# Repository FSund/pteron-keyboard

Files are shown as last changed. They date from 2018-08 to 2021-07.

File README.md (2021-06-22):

# pteron keyboard
An ergonomic keyboard heavily inspired by the [Atreus](https://github.com/technomancy/atreus), [Iris](https://github.com/keebio/iris-case) and [Atreis](https://github.com/dekonnection/atreis) keyboards.

The name *Pteron* is the Ancient greek word for wing (and feather). This was inspired by *Chiroptera*, the scientific name (or order) of bats.
> The name “Chiroptera” derives from Ancient Greek: χείρ – cheir, “hand” and πτερόν – pteron, “wing”.
https://en.wikipedia.org/wiki/Bat#Etymology

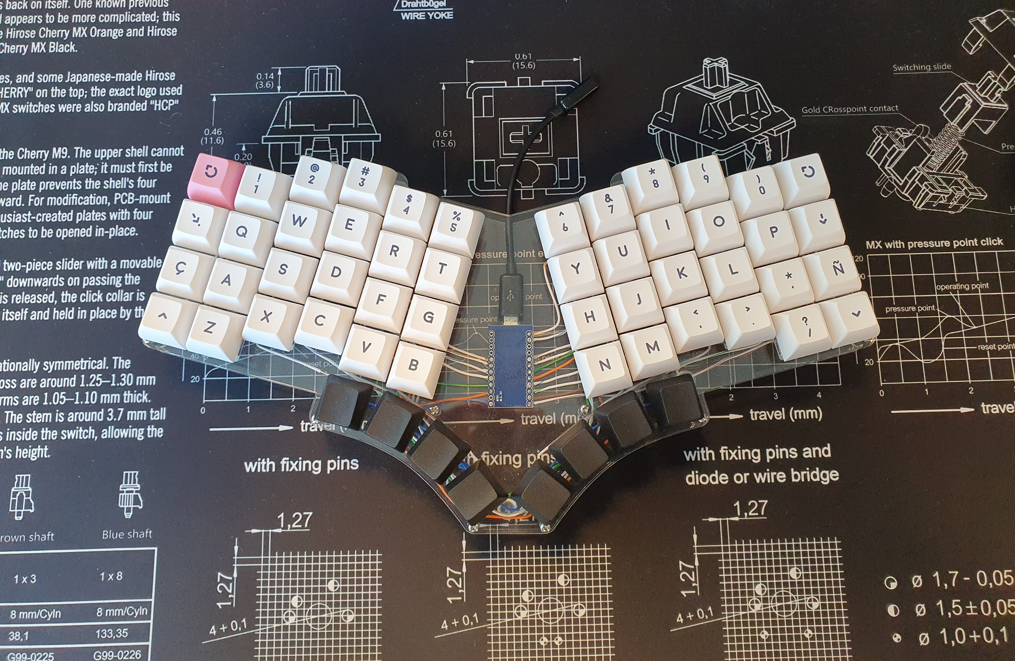
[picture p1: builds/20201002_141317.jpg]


Check the [builds](/builds/builds.md) folder for more photos. 
The 56-key version shown in the photo above is built using 9 mm brass spacers. It can theoretically be built using spacers as small as 5 mm, but that requires very strict cable management.

## Related projects
- PCB and acrylic case for the 56-key Pteron: https://github.com/kraken-jokes/pteron-pcb
- 36-key split version with PCB and acrylic case designs: https://github.com/harshitgoel96/pteron36-split-keyboard

## Styles
#### 38 keys
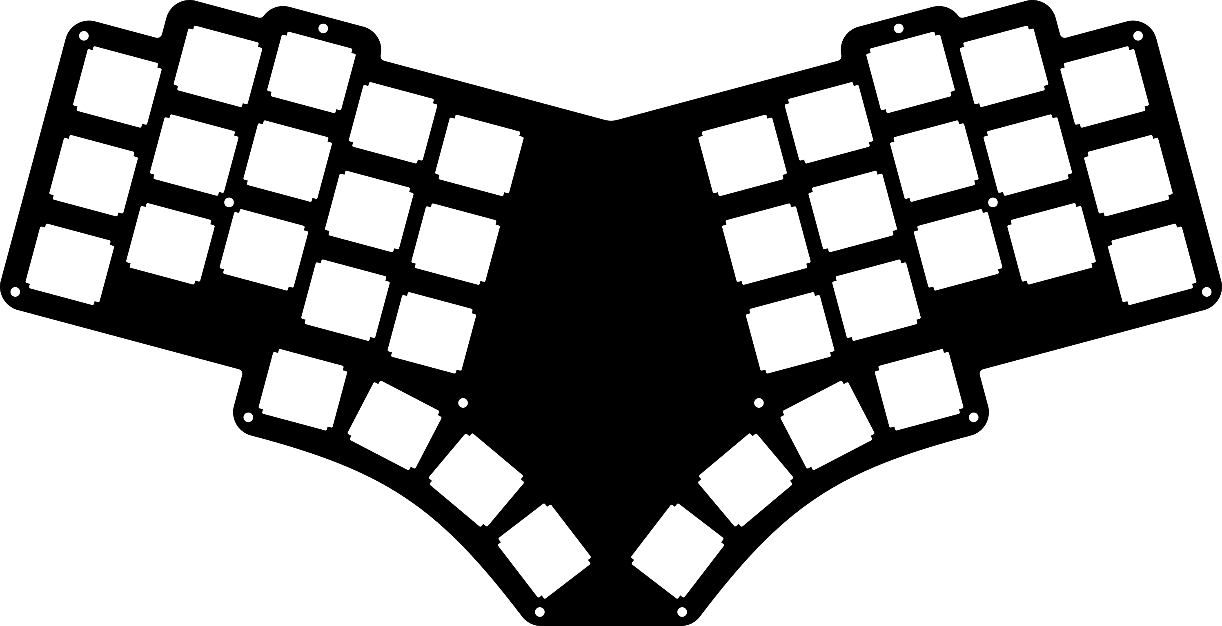
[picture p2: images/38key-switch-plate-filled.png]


#### 44 keys
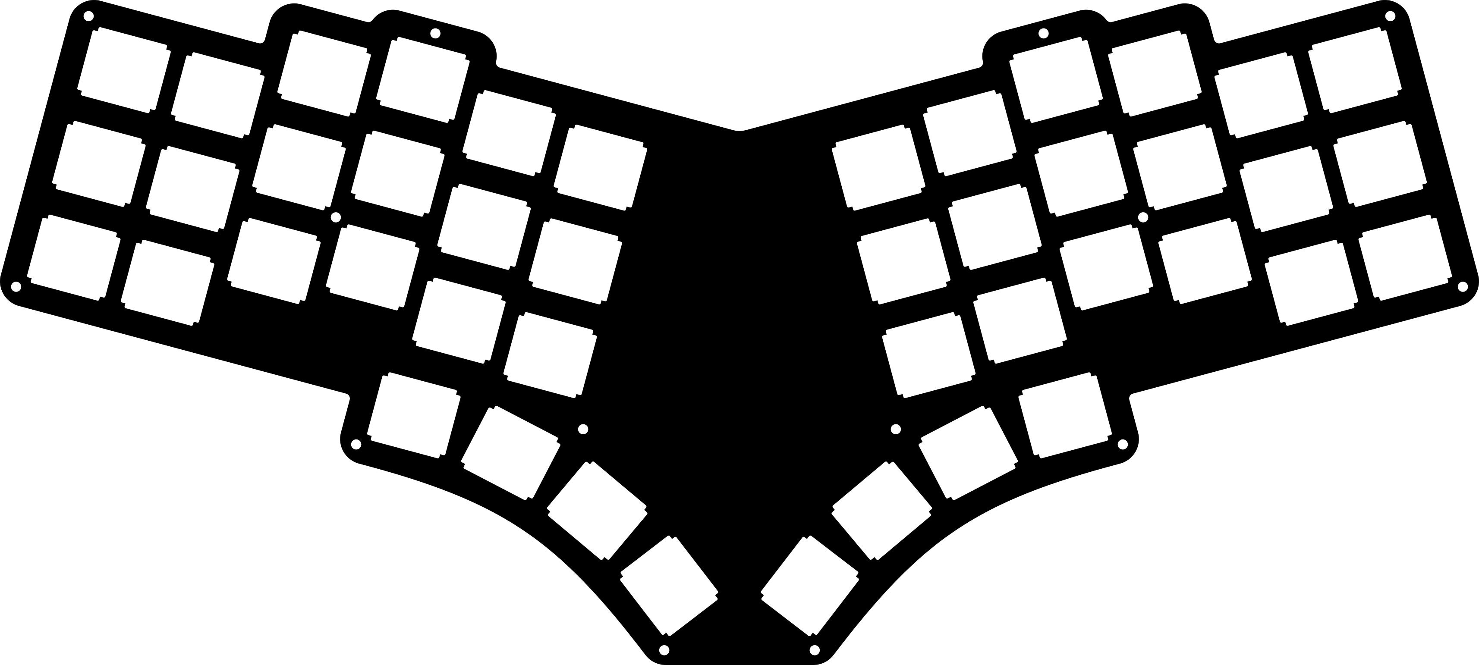
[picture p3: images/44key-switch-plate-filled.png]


#### 56 keys
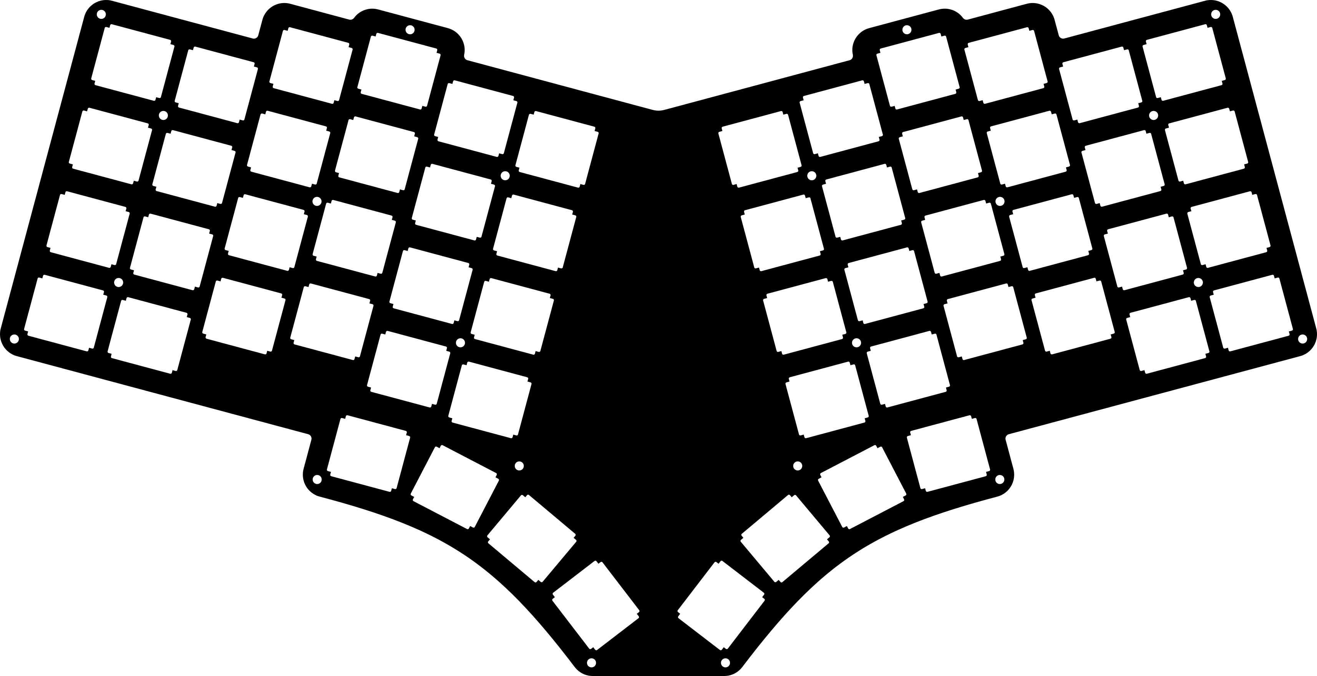
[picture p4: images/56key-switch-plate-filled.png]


## Laser cutting
The default switch plate is designed for laser cutting with a kerf of 0.1 mm. The switch holes are designed for Cherry MX style switches, and should allow for switch top removal on both Cherry MX/Gateron/etc. and Kailh BOX switches. 

There is an alternative switch plate with square holes (`case/switch-plate-square-holes.svg`), which does not allow switch top opening, but which might add some stability to the switches.

I would recommend using 3 mm thick acrylic for stiffness, which means that the switches have to be glued in, since Cherry MX-style switches are designed for a plate thickness of ~1.5 mm.

#### Conversion
The .svg-files can be converted to dxf by first saving as .eps (via for example [Inkscape](https://inkscape.org/)) and then using the following [pstoedit](http://pstoedit.net/) command

    pstoedit -f "dxf_s: -mm -splineasbezier" infile.eps outfile.dxf

## Firmware
Firmware is available here: https://github.com/qmk/qmk_firmware/tree/master/keyboards/handwired/pteron

## Design
The initial inspiration was the [Atreis](https://github.com/dekonnection/atreis) keyboard, but I wanted some more stagger on the ring and pinky fingers. I ended up with a stagger of -0.7 u for the two outer columns, followed by -0.2 u, 0, -0.3 u and -0.4 u. I also removed the top thumb key, and added a key to the thumb cluster. 

## Licensing
> These works are licensed under the Creative Commons Attribution-ShareAlike 4.0 International License. To view a copy of this license, visit http://creativecommons.org/licenses/by-sa/4.0/ or send a letter to Creative Commons, PO Box 1866, Mountain View, CA 94042, USA.

This means you can run Group Buys of these designs, as long as you credit where the design came from (this repo).

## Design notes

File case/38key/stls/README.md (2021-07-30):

# 3D printable case designs for pteron38

You can use a couple of different combinations to build this case.

Either use:
* bottom-case.stl and switch-plate.stl
* bottom-plate.stl and switch-plate-case.stl

You can also use the rotaryencoder-plate.stl to use the center two switch holes for rotary encoders.

See the images:

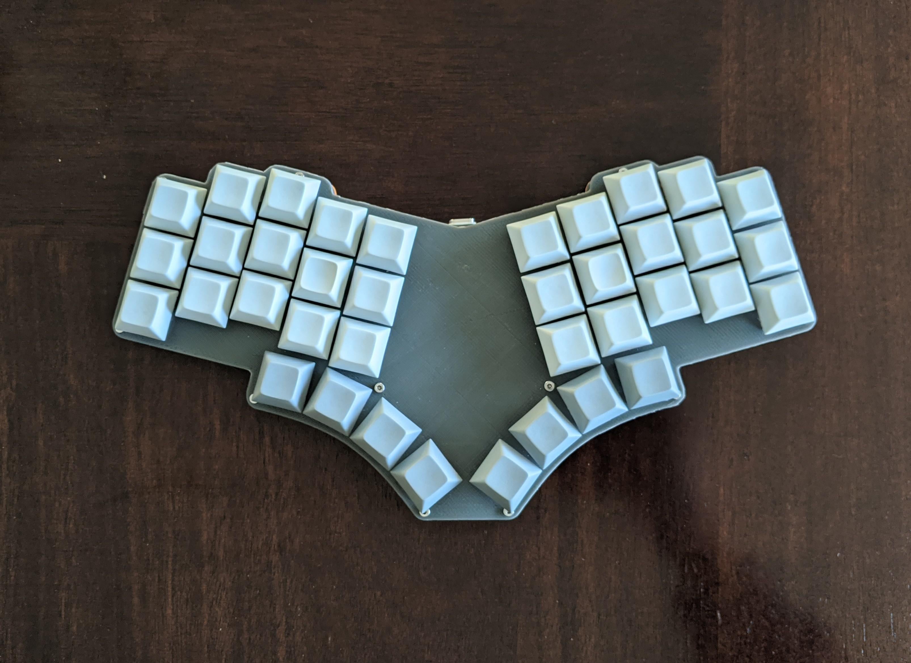
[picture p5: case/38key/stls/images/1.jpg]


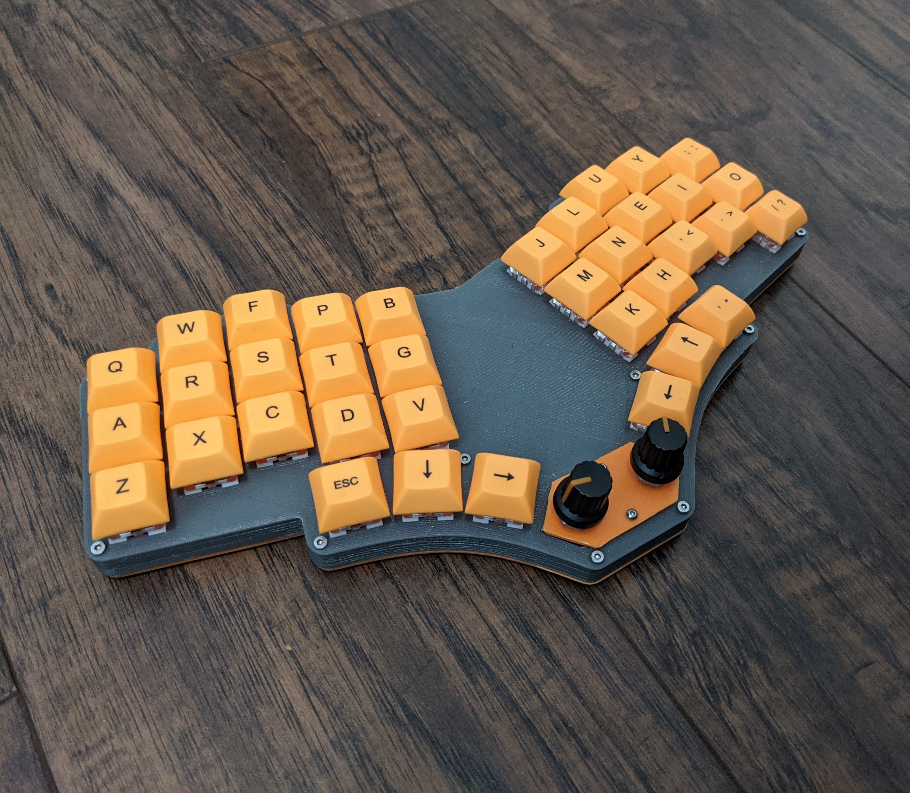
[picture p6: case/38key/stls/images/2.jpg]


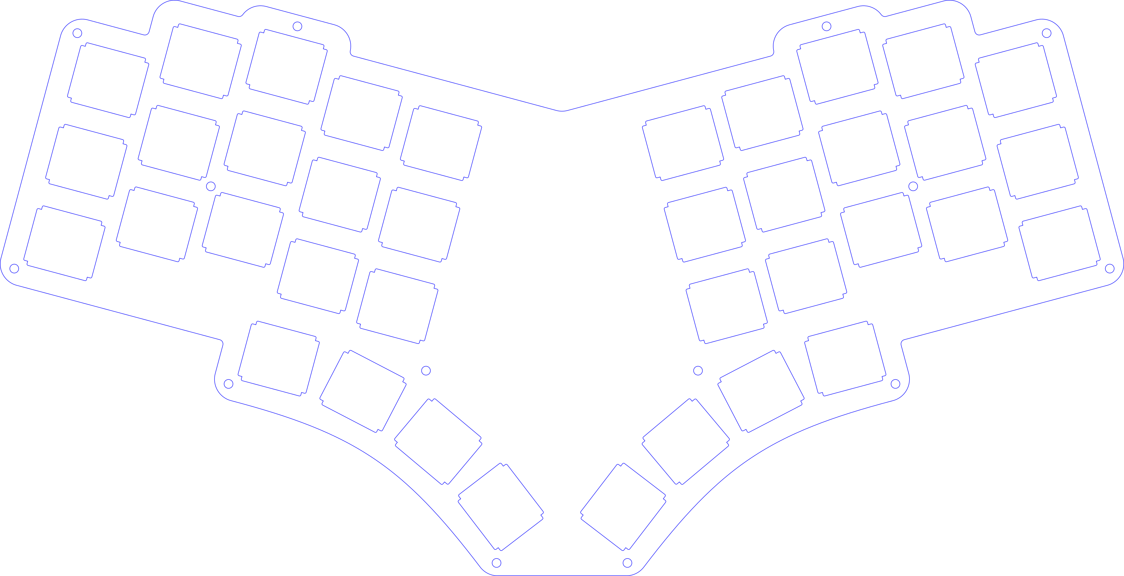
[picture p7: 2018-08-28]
images/38key-switch-plate.png

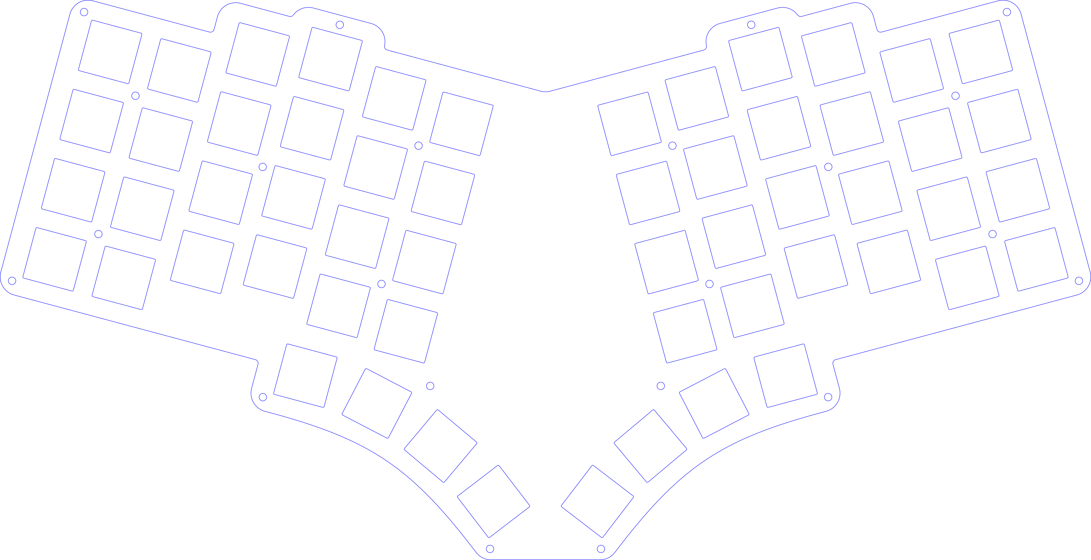
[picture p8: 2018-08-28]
images/56key-switch-plate-square-holes.png

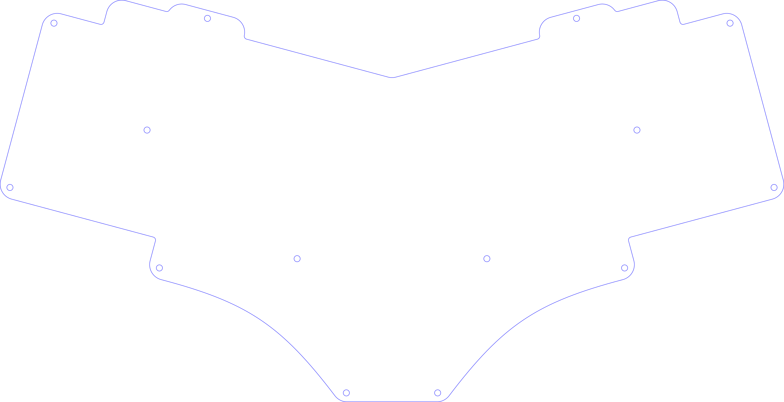
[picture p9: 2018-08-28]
images/38key-back-plate.png

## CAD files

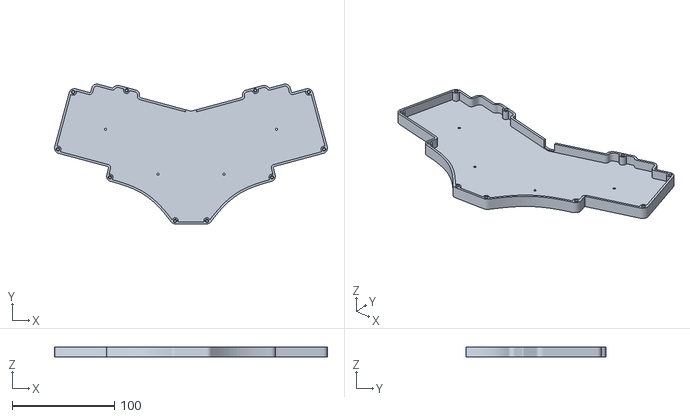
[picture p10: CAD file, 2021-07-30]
case/38key/stls/bottom-case.stl
266.7 x 136.7 x 10.0

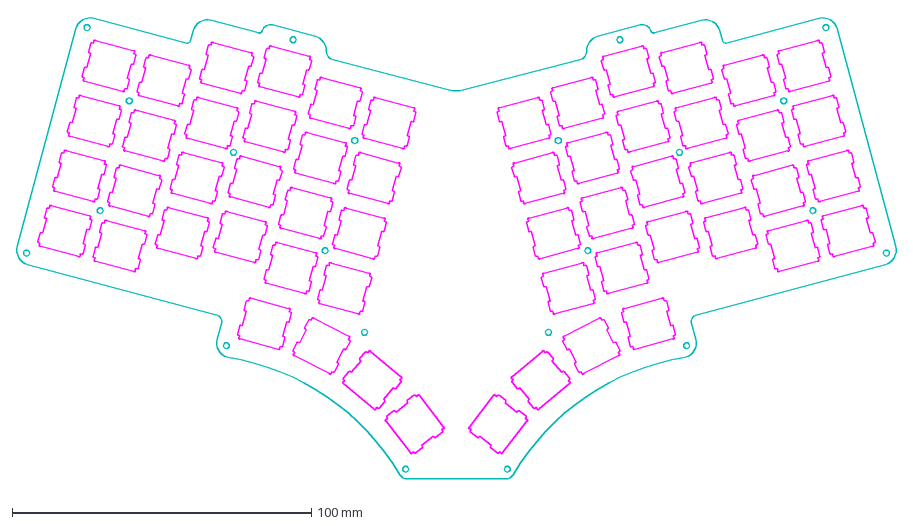
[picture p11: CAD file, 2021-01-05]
case/56key/Pteron56_MXholes 7mm padding.dxf
294.1 x 156.8 mm

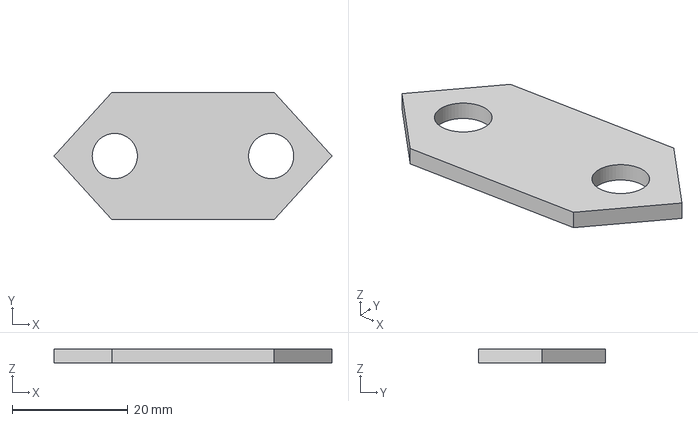
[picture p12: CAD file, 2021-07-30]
case/38key/stls/rotaryencoder-plate.step
48.0 x 22.0 x 2.40 mm

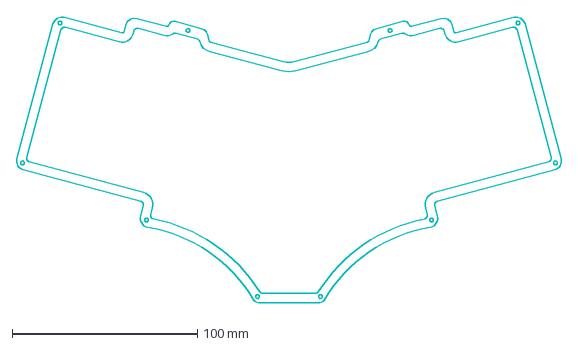
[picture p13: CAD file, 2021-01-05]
case/56key/Pteron56_stack plate 7mm padding.dxf
294.1 x 156.8 mm

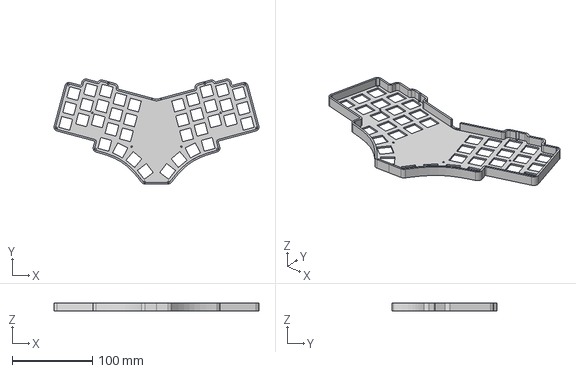
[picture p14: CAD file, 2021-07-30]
case/38key/stls/switch-case.step
255.3 x 130.8 x 9.60 mm

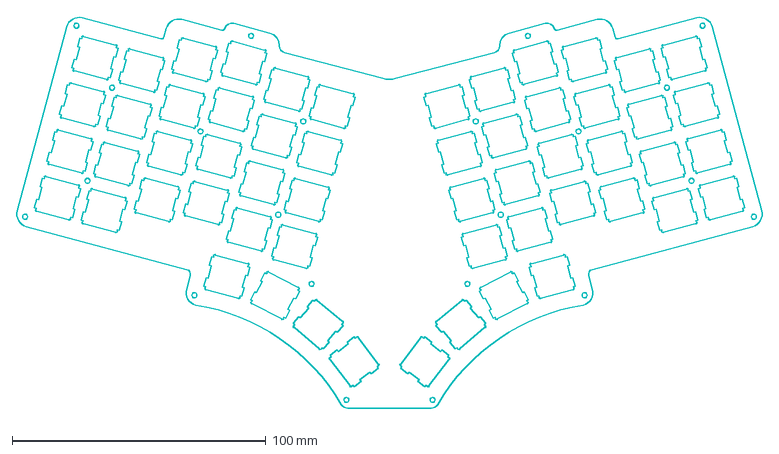
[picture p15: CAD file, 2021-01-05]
case/56key/Pteron56_sharpMXholes 7mm padding.dxf
294.1 x 156.8 mm

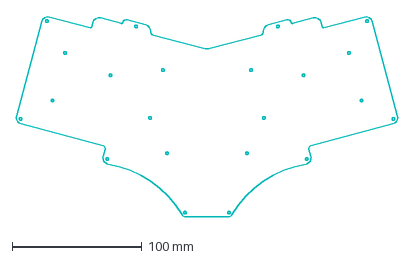
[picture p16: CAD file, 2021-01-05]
case/56key/Pteron56_base 7mm padding.dxf
294.1 x 156.8 mm

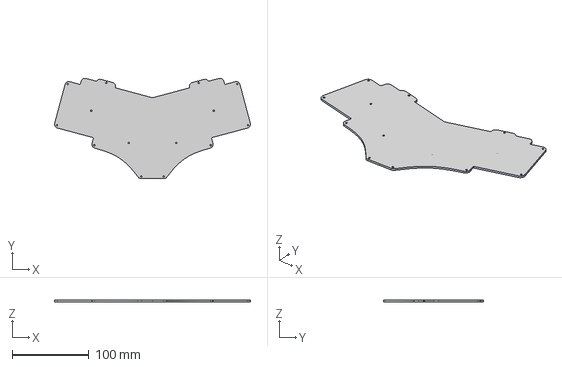
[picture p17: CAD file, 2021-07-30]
case/38key/stls/bottom-plate.step
255.3 x 130.8 x 2.00 mm

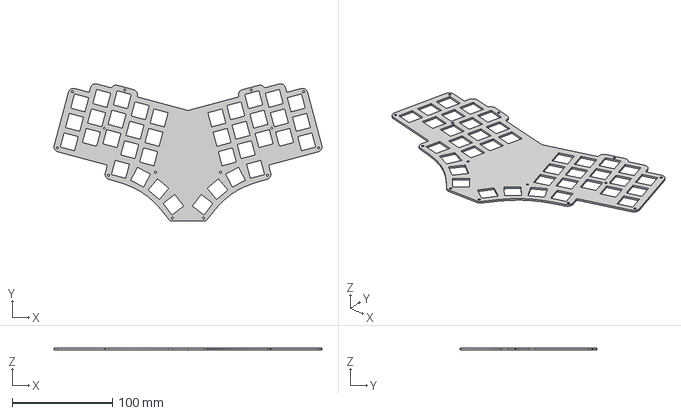
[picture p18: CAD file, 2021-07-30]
case/38key/stls/switch-plate.step
266.8 x 136.7 x 1.60 mm

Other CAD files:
case/38key/stls/switch-plate-case.stl
case/38key/stls/bottom-plate.stl
case/38key/stls/rotaryencoder-plate.stl
case/38key/stls/switch-plate.stl

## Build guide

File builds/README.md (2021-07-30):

# FSund
The first prototype, built by me.

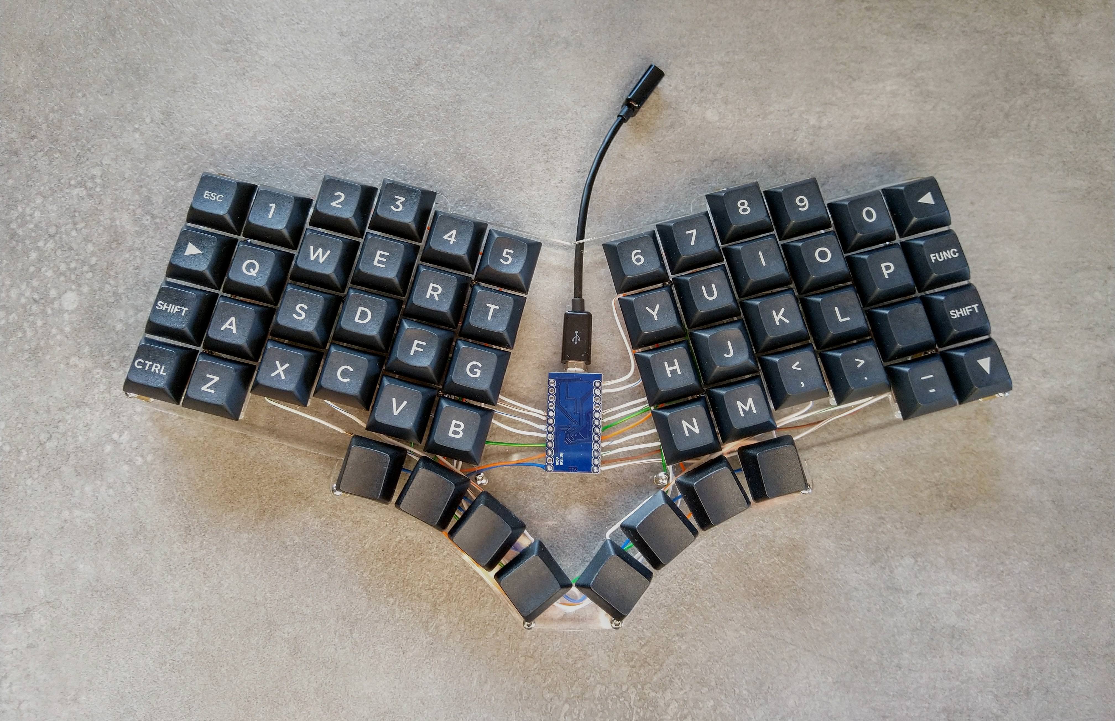
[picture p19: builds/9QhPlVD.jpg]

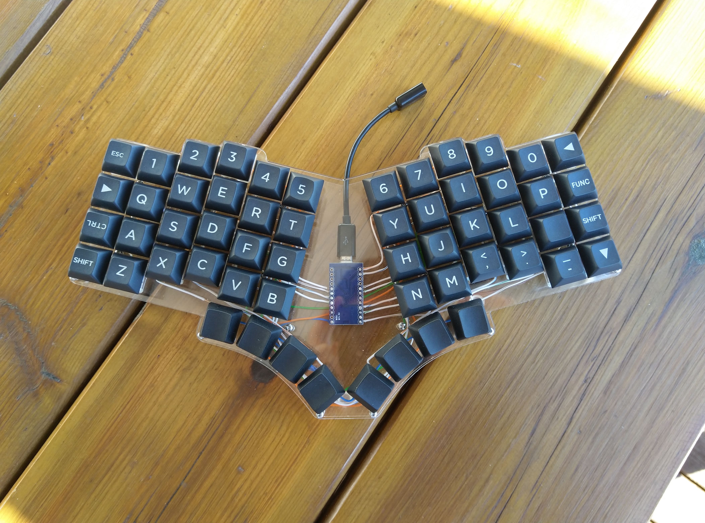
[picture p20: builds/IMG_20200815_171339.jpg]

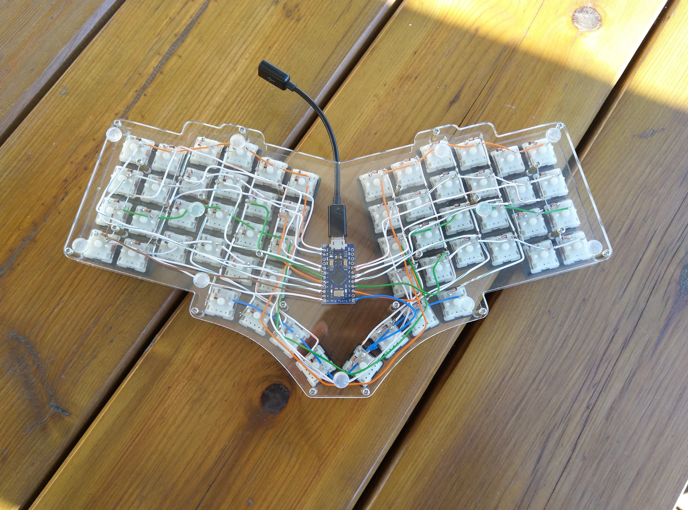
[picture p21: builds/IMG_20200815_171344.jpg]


# poteyro
Built by [/u/poteyro](https://www.reddit.com/user/poteyro) over on [reddit](https://www.reddit.com/r/MechanicalKeyboards/comments/i9eaw7/inoculated_for_safety_pteron38/).

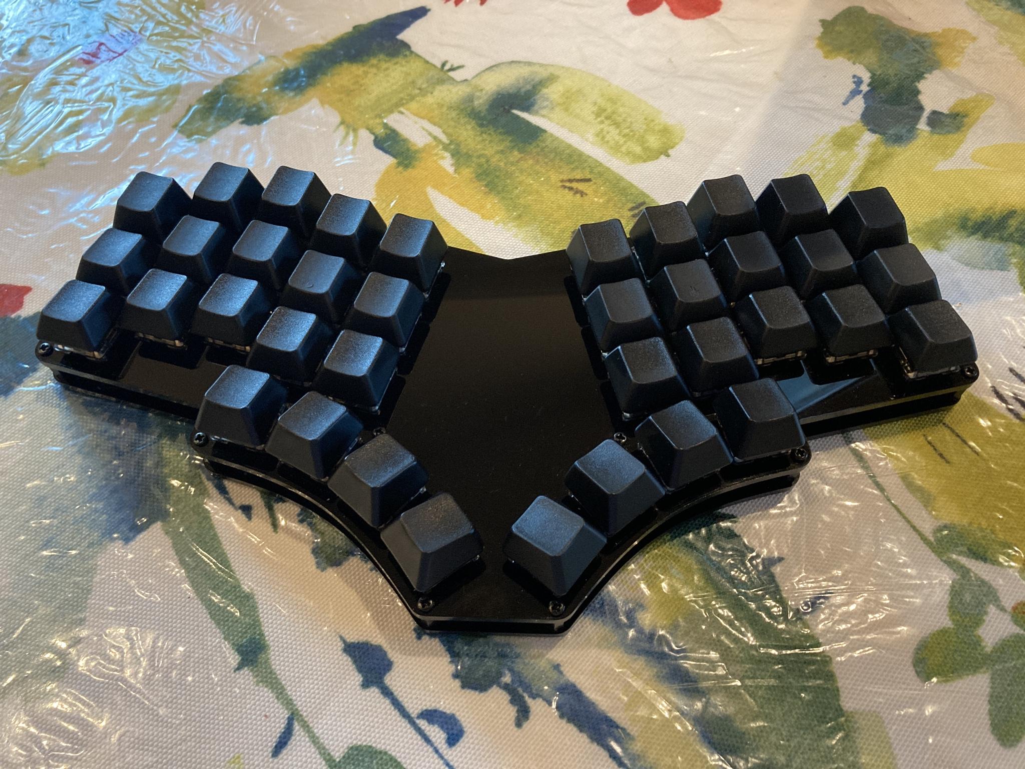
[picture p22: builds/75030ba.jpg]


# Kraken-Jokes
Built by [Kraken-Jokes](https://github.com/Kraken-Jokes) on [facebook](https://www.facebook.com/MooreKeyboards/posts/127088362516273)

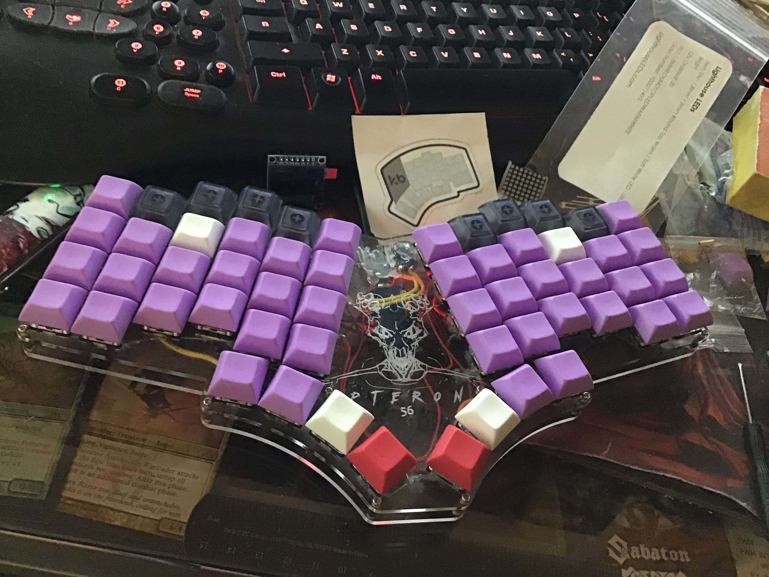
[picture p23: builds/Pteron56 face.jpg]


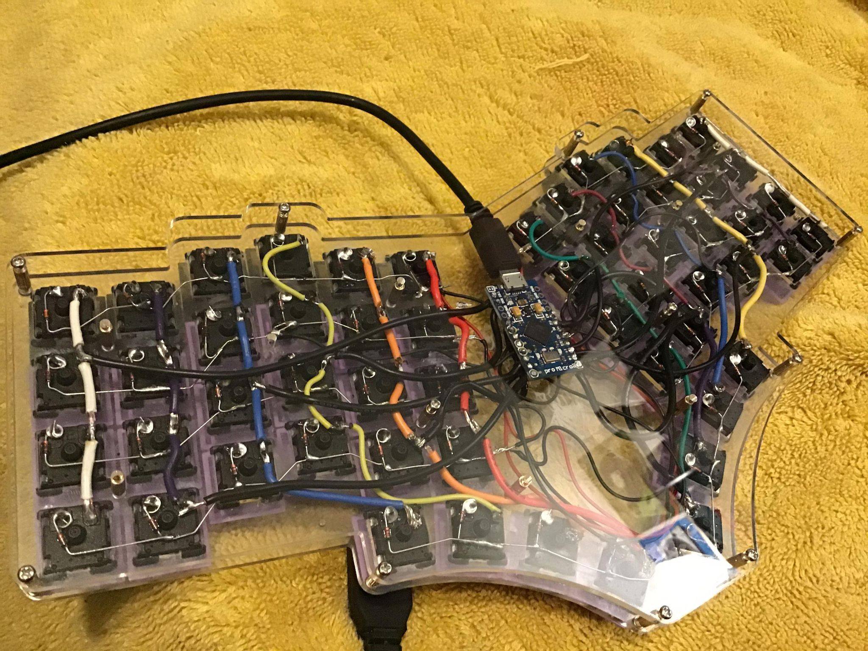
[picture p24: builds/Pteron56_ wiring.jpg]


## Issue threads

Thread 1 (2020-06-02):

Standoff Size

fidelcoria, 2020-06-02:
What size standoffs are you using for the plates?

FSund, 2020-06-02:
That's a good question. I'll dig up the board later today and take some measurements. Perhaps I should include a bill of materials in the readme.

FSund, 2020-10-02:
The one in the photo in the readme is built using 9mm brass spacers, but can theoretically be built with spacers as low as 5 mm. I would probably go for at least 8 mm if you're not very familiar with handwiring.

Closed 2020-10-02.

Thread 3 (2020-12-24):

Design alterations

Kraken-Jokes, 2020-12-24:
Howdy!
Awesome design, I've built two so far and love them fiercely. In building those I decided that my 'share and share alike' was going to be recreating the files in .dxf format.
I have the files for the Pteron56 ready to go, I just wanted to start an issue to see if sending that pull request would be cool.
I also have an image of my build I'd like to add

FSund, 2020-12-24:
Cool! I never got further than the one prototype, so I get very excited when I see other people liking the design.

Instructions for converting to dxf is included in the readme, but including files ready to go might me a good idea. A PR is always welcome. I might not have time to look at in a couple of days though.

Pictures of builds are of course very welcome!

Kraken-Jokes, 2020-12-24:
Sounds good!
I've also made a version of the 56 that has encoder, backlight, and teensy2.0 support. Since it's different enough I'm calling it pteron_v2 on my local machine, but wanted to get your input on that name before I put it on github (I don't want to take the name if you're planning on using it).

FSund, 2021-01-05:
Sorry for the late reply here, just noticed your commend. Go ahead with pteron_v2, that sounds like a cool project.

Closed 2021-01-05.

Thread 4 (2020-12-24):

TODO: Design pcb

FSund, 2020-12-24:
This is a long-term goal, which includes me first learning how to design pcb's, so it will probably never happen 😅

Kraken-Jokes, 2021-02-17:
I can take a crack at it. I'm in the same boat of needing to learn first but a PCB for this thing would really make the Pteron take off 😆

FSund, 2021-02-17:
That would be really cool. Let me know how it goes!

Kraken-Jokes, 2021-03-21:
Alright it's been a long, arduous path full of pulling out my hair and cursing at how things don't work how I assume they should, but I've got it. True to the Pteron project, the first prototype is getting made for a pro micro with only diodes, and switches needed. Basic, but (assuming again) very functional. Here's a render of how it turned out.
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
I was planning to wait on the pull request until I could verify the viability of the design, but if you want to check it out before then (also an embedded 32u4/ USB-C board with THT LEDs in progress) you can look at my fork of pteron-keyboard.
The embedded version is the Pteron56v0, the pro micro drop in version is Pteron56v0-PRO MICRO

FSund, 2021-03-22:
Thanks a lot for all your hard work, that looks really cool!

Let me know how the prototype works out. I'll definitely have to get a couple of these!

FSund, 2021-04-06:
Work on the PCB version continues here: https://github.com/kraken-jokes/pteron-pcb

Thanks @Kraken-Jokes !

Closed 2021-04-06.

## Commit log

2018-07-25 Added case files.
2018-07-25 Added 2mm screw holes.
2018-07-25 Added version with square switch holes.
2018-08-28 Increased distance between halves by 3mm to avoid issues with DSA keycaps.
2021-01-05 Kraken jokes' Pteron56 files (#5)
    * Pteron56 built by Kraken-Jokes
    Laser cut 3mm acrylic with custom logo/ art laser etching.
    Gateron Red switches, pro micro clone, 8mm spacers
    * Adding no-kerf .dxf files
    Adding no-kerf files, mx style opening holes with 7mm padding between the switch hole and edge of the keyboard. Use this style only for laser cut materials that are 1.5mm, or .06" thickness.
    Base is the base. Stack plates are just perimeter plates for adding thickness to the keyboard. The stack plates are not needed unless you want to add them.
    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
    [Pteron56_MXholes 7mm padding.dxf, Pteron56_base 7mm padding.dxf, Pteron56_sharpMXholes 7mm padding.dxf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]
2021-04-06 Add link to PCB version
2021-07-29 Added case stls and example images
    [bottom-case.stl, bottom-plate.stl, rotaryencoder-plate.stl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]
2021-07-29 added step files for pteron38 case as well
    [bottom-plate.step, rotaryencoder-plate.step, switch-case.step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]
